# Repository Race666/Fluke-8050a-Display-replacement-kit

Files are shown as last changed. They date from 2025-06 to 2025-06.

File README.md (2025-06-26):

# Yet another Fluke 8050a Display replacement kit

There already several cool other projects for a creating a new display for this type of multimeter where the LCD display is broken.

Here are some examples. 
* [vondervotteimittiss.de](https://www.vondervotteimittiss.de/post/a-new-led-display-for-a-fluke-8050a-multimeter)
* [sps-wagner.de](https://www.sps-wagner.de/Sonstiges/8050A.html)
* [hackaday.com](https://hackaday.com/2022/06/17/hacking-a-new-display-into-a-fluke-8050a-multimeter/)

Based on their work I created my own version. My goal was to create a solution that is easy to install.

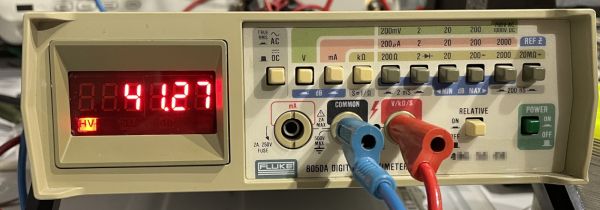
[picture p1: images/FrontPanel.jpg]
My LED Solution


 So the honer for reverse engineering of the 8050a goes to [Michael Damkier](https://www.vondervotteimittiss.de/) and also to [jasonacox](https://github.com/jasonacox) for the TM1637TinyDisplay library on which my project based.

My project uses an Atmel atmega328p microcontroller which I used for other [projects](https://github.com/Race666/masterclock) too.

The precompiled firmware file could be found [here](./src/pio/.pio/build/ATmega328P/firmware.hex)

Flash the with these fuses (8MHz internal clock)
```
avrdude -c usbtiny -p atmega328p -U lfuse:w:0x62:m -U hfuse:w:0xDE:m -U efuse:w:0x05:m -U flash:w:./src/pio/.pio/build/ATmega328P/firmware.hex
```

Overview over the project folders
| Folder  | Description  |
|---|---|
|[/images](./images)|Images for this wiki|
|[/LogicAnalysis](./LogicAnalysis)|Images with Pulseview Screenshots|
|[/pcb](./pcb)|KiCad project with schematic and PCB|
|[/src](./src)|Platform IO firmware project for atmega328p|
|[/stl](./stl)|3D Data for display- and heatsink holder|

The project has multipe parts

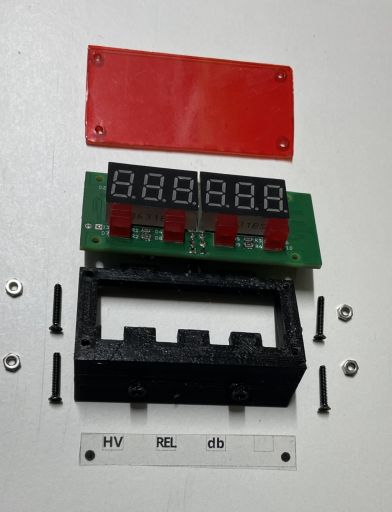
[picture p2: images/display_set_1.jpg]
Parts overview Display set

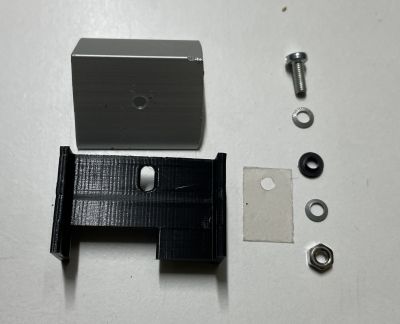
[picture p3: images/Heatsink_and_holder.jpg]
Parts overview Heatsink for -5V regulator

* The platform IO firmware [project](./src/) for the atmega328p microcontroller
* 4 Layer display [PCB](./pcb/) create with KiCad
* A [Display holder](./stl/Fluke%208050a%20Displayhalter.stl) STL for printing by a 3D printer so that the display exctly fits in :-)
* A [holder](./stl/Halter%20Kühlkörper.stl) for a heat sink for the -5V regulator on the mainboard. The Display board consumes more power then the LCD Display so the -5V regulator needs some cooling

In addition to [vondervotteimittiss.de](https://www.vondervotteimittiss.de/post/a-new-led-display-for-a-fluke-8050a-multimeter) I also analysed the logic of the J1 connector from the Fluke display board. I traced the signals by a Hantek logic analyser and pulseview. The traces can be shows [here](./LogicAnalysis/) and looks like this example (Output Pins are the atmega328p outputs for LED's):

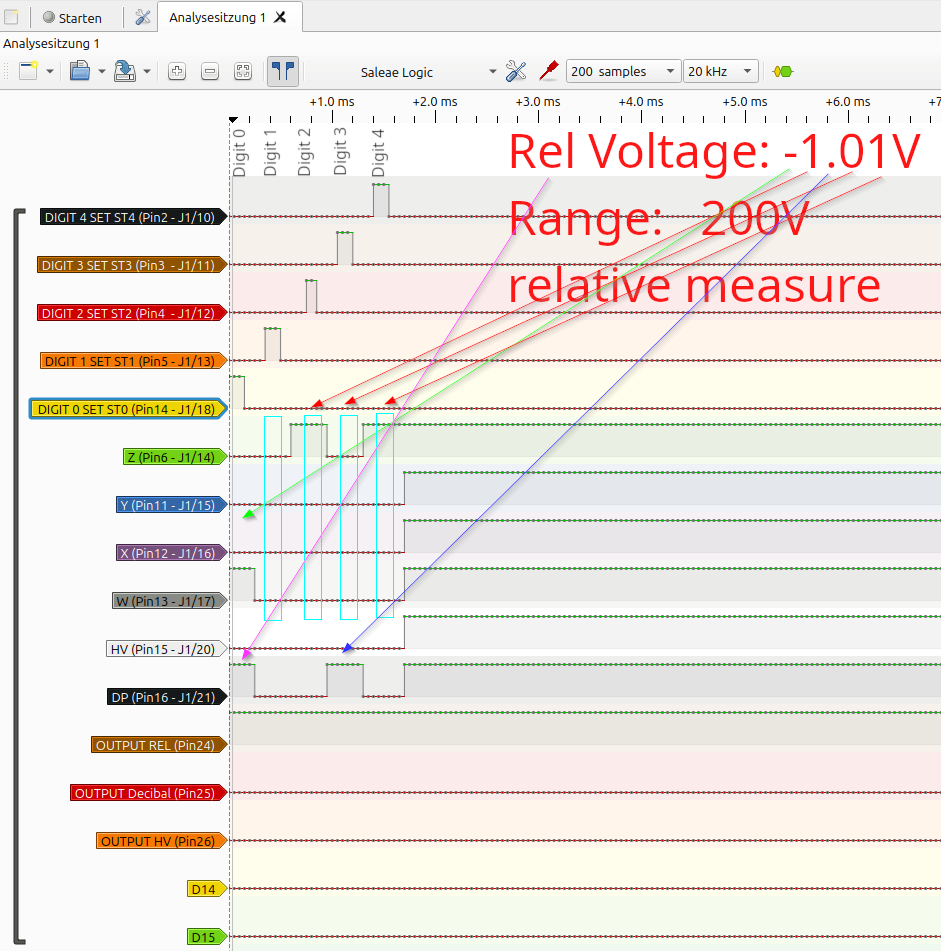
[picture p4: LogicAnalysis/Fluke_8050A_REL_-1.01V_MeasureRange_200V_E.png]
pulseview output


It's always the same format. The DIGIT (select) Pins are corrosponding to the Fluke Display from left to right. 

    Fluke Digit Count
                 _    _    _    _
             |  | |  | |  | |  | | 
         +/-     -    -    -    -
             |  | |  | |  | |  | | 
                 ͞     ͞     ͞     ͞        
     Digit  0    1    2    3    4    

When one of the digit pins get's high the data are submitted by the Pins Z, Y, X, W, HV, DP. A schematic/Service Manual of the Fluke 8050a can be found [here](https://xdevs.com/doc/Fluke/FLUKE%208050A%20Instruction.pdf) or [here](http://manuals.chudov.com/Fluke-8050A.pdf). See Page 7-4, 7-5, the DIGITx signal are labeled as STx in the schematic.

When DIGIT 1-4 are set the Pins Z, Y, X, W represents(as 4Bits) the number which is show at the display. While Z is the LSB (Least Significant Bit) and W the MSB (Most Significant Bit) and the DP signals where to position the decimal point in the display. The decimal point must be shown left to the current transmitted digit. For example (see logic trace) if the DP flag is set in digit 3 then the decimal point is between digit 2 and 3.

DIGIT 0 transfer some more information over Z, Y, X, W, HV, DP.
* HV signals the High Voltage info
* DP in digit 0 signals a relative measure/the relative measure button is locked
* When Z is set "1" is shown at digit postition 0
* When X is not set the measure is negative

| | | | |
|---|---|---|---|
| W=1 | X=1 | Y=0 | Voltage/Current measure |
| W=1 | X=0 | Y=0 | negative Voltage/Current measure | 
| W=1 | X=0 | Y=1 | Decibel measure |
| W=0 | X=0 | Y=0 | Resistor measure |

## The LED display board
The LED display board is a 4 layer PCB created by [KiCad](https://www.kicad.org "Great tool"). Where I used very common parts:
* Atmega328p microcontroller
* TM1637 LED 7 segment driver
* 3361BS 7 segment displays

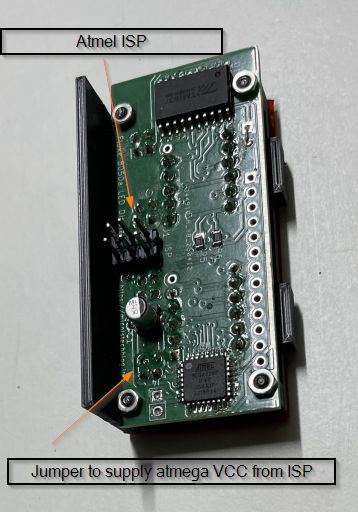
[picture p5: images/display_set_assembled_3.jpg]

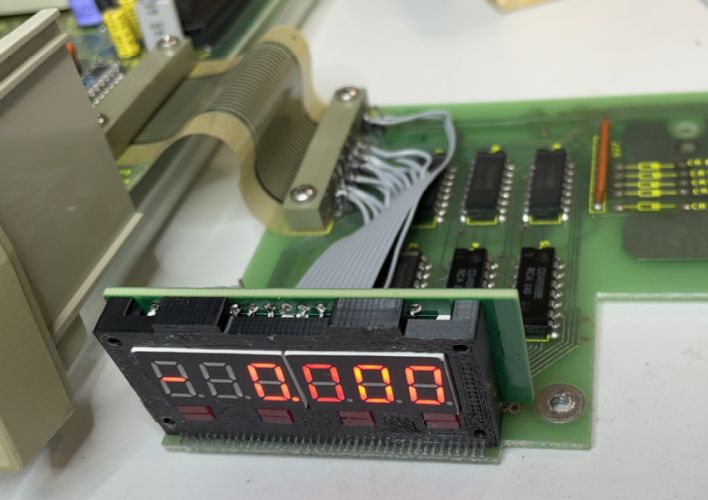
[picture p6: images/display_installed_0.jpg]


The display board has 4 Leds below the 7 segment displays to signal high voltage, decibel and relative measure.

The 6 Pin header is an atmega ISP port.
| Pin | Signal |
|---|---|
|1| MISO |
|2|VCC|
|3|SCK|
|4|MOSI|
|5|RST|
|6|GND|

The header pins for connecting to the fluke display board are ordered so wiring is simple:
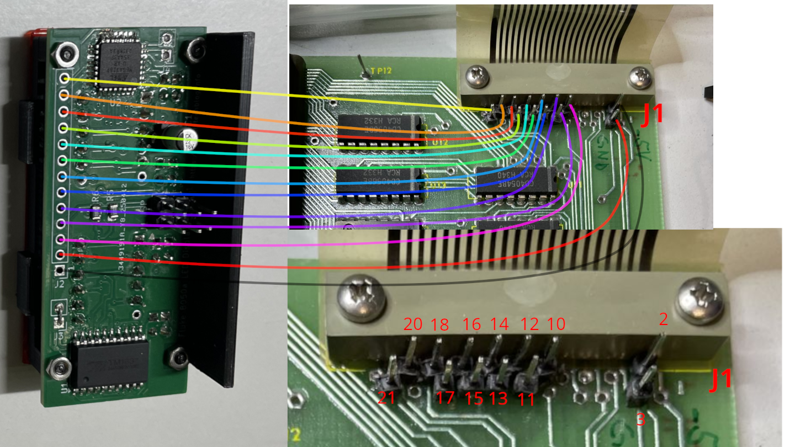
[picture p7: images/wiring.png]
Wiring


## 3D printer parts

### Holder for the PCB

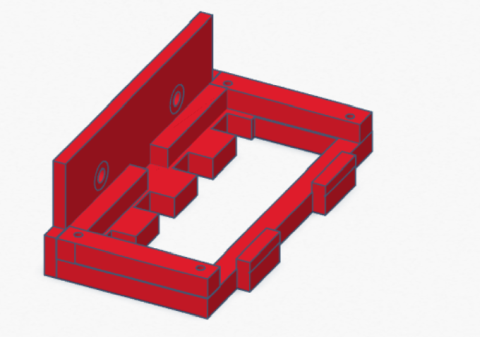
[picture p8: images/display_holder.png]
PCB/Display Holder


### Heatsinkholder/stabilizer
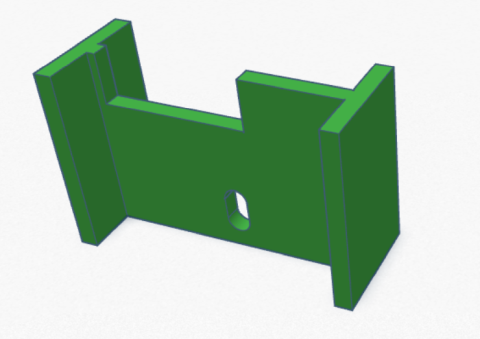
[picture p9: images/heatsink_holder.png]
Heatsink Holder

Heatsink Holder
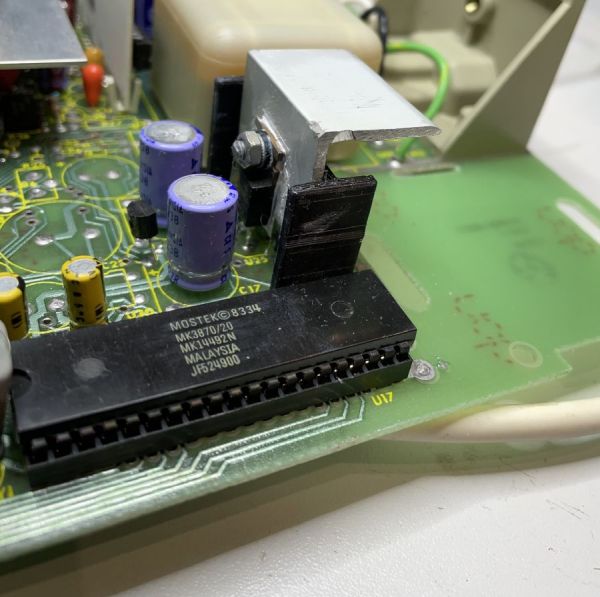
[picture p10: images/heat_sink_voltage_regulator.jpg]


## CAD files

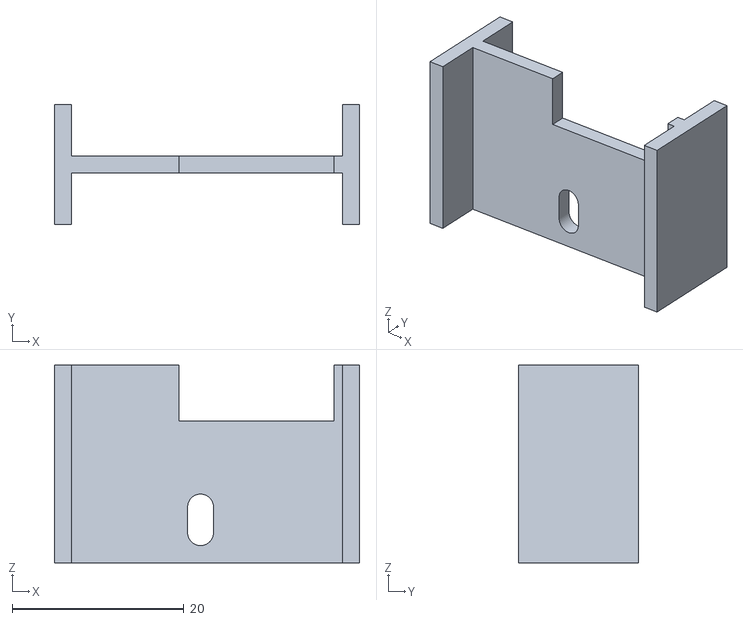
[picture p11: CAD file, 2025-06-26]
stl/Halter Kühlkörper.stl
35.5 x 14.0 x 23.0

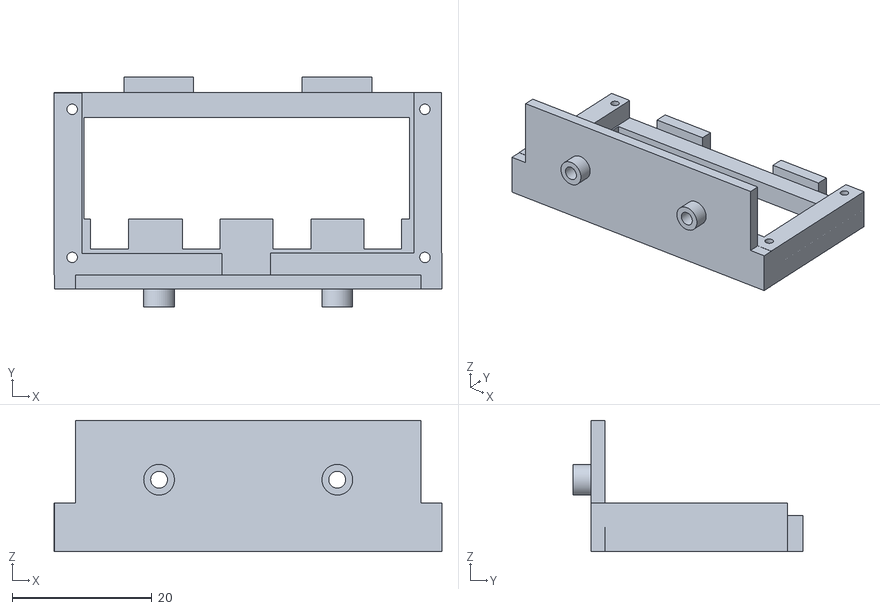
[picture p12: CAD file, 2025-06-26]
stl/Fluke 8050a Displayhalter.stl
55.5 x 33.0 x 18.8

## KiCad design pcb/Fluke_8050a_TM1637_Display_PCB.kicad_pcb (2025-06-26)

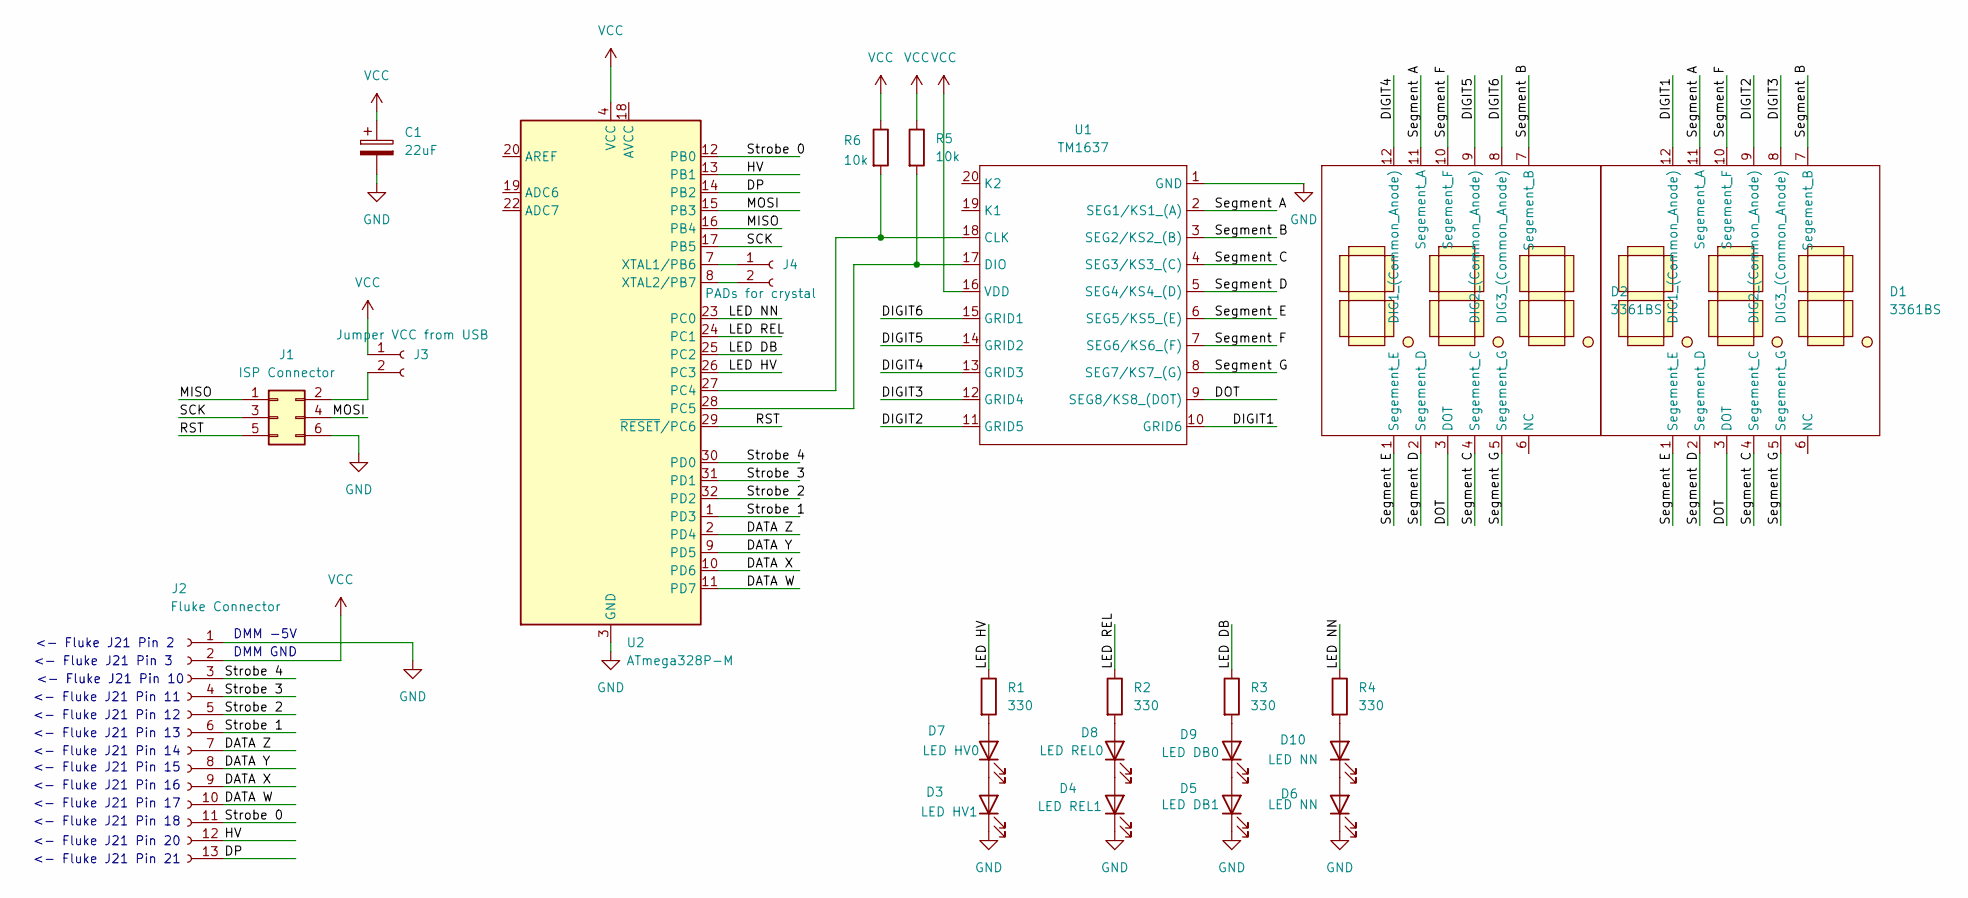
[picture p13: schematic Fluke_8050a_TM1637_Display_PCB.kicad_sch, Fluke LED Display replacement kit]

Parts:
C1: 22uF; CP_Elec_4x5.8
D1, D2: 3361BS; 3361xS
D3: LED HV1; LED 5x2mm Exact
D4: LED REL1; LED 5x2mm Exact
D5: LED DB1; LED 5x2mm Exact
D6, D10: LED NN; LED 5x2mm Exact
D7: LED HV0; LED 5x2mm Exact
D8: LED REL0; LED 5x2mm Exact
D9: LED DB0; LED 5x2mm Exact
J1: ISP Connector; PinHeader_2x03_P2.54mm_Vertical
J2: Fluke Connector; PinHeader_1x13_P2.54mm_Vertical
J3: Jumper VCC from USB; PinHeader_1x02_P2.54mm_Vertical
J4: PADs for crystal; PinHeader_1x02_P2.54mm_Vertical
R1, R2, R3, R4: 330; R_0805_2012Metric
R5, R6: 10k; R_0805_2012Metric
U1: TM1637; SOP-20_7.5x12.8mm_P1.27mm
U2: ATmega328P-M; LQFP-32_7x7mm_P0.8mm

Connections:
/DATA W: J2.10, U2.11 (PD7)
/DATA X: J2.9, U2.10 (PD6)
/DATA Y: J2.8, U2.9 (PD5)
/DATA Z: J2.7, U2.2 (PD4)
/DIGIT1: D1.12 (DIG1_(Common_Anode)), U1.10 (GRID6)
/DIGIT2: D1.9 (DIG2_(Common_Anode)), U1.11 (GRID5)
/DIGIT3: D1.8 (DIG3_(Common_Anode)), U1.12 (GRID4)
/DIGIT4: D2.12 (DIG1_(Common_Anode)), U1.13 (GRID3)
/DIGIT5: D2.9 (DIG2_(Common_Anode)), U1.14 (GRID2)
/DIGIT6: D2.8 (DIG3_(Common_Anode)), U1.15 (GRID1)
/DOT: D1.3 (DOT), D2.3 (DOT), U1.9 (SEG8/KS8_(DOT))
/DP: J2.13, U2.14 (PB2)
/HV: J2.12, U2.13 (PB1)
/LED DB: R3.1, U2.25 (PC2)
/LED HV: R1.1, U2.26 (PC3)
/LED NN: R4.1, U2.23 (PC0)
/LED REL: R2.1, U2.24 (PC1)
/MISO: J1.1, U2.16 (PB4)
/MOSI: J1.4, U2.15 (PB3)
/RST: J1.5, U2.29 (~RESET/PC6)
/SCK: J1.3, U2.17 (PB5)
/Segment A: D1.11 (Segement_A), D2.11 (Segement_A), U1.2 (SEG1/KS1_(A))
/Segment B: D1.7 (Segement_B), D2.7 (Segement_B), U1.3 (SEG2/KS2_(B))
/Segment C: D1.4 (Segement_C), D2.4 (Segement_C), U1.4 (SEG3/KS3_(C))
/Segment D: D1.2 (Segement_D), D2.2 (Segement_D), U1.5 (SEG4/KS4_(D))
/Segment E: D1.1 (Segement_E), D2.1 (Segement_E), U1.6 (SEG5/KS5_(E))
/Segment F: D1.10 (Segement_F), D2.10 (Segement_F), U1.7 (SEG6/KS6_(F))
/Segment G: D1.5 (Segement_G), D2.5 (Segement_G), U1.8 (SEG7/KS7_(G))
/Strobe 0: J2.11, U2.12 (PB0)
/Strobe 1: J2.6, U2.1 (PD3)
/Strobe 2: J2.5, U2.32 (PD2)
/Strobe 3: J2.4, U2.31 (PD1)
/Strobe 4: J2.3, U2.30 (PD0)
GND: C1.2, D3.1 (K), D4.1 (K), D5.1 (K), D6.1 (K), J1.6, J2.1, U1.1 (GND), U2.3 (GND), U2.5 (GND), U2.21 (GND), U2.33 (GND)
unnamed: D3.2 (A), D7.1 (K)
unnamed: D4.2 (A), D8.1 (K)
unnamed: D5.2 (A), D9.1 (K)
unnamed: D7.2 (A), R1.2
unnamed: D8.2 (A), R2.2
unnamed: D9.2 (A), R3.2
unnamed: D10.2 (A), R4.2
unnamed: D6.2 (A), D10.1 (K)
unnamed: J1.2, J3.2
unnamed: J4.1, U2.7 (XTAL1/PB6)
unnamed: J4.2, U2.8 (XTAL2/PB7)
unnamed: R6.2, U1.18 (CLK), U2.27 (PC4)
unnamed: R5.2, U1.17 (DIO), U2.28 (PC5)
VCC: C1.1, J2.2, J3.1, R5.1, R6.1, U1.16 (VDD), U2.4 (VCC), U2.6 (VCC)

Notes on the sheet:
<- Fluke J21 Pin 17
<- Fluke J21 Pin 12
<- Fluke J21 Pin 13
<- Fluke J21 Pin 20
<- Fluke J21 Pin 18
<- Fluke J21 Pin 21
<- Fluke J21 Pin 16
<- Fluke J21 Pin 11
DMM -5V
DMM GND
<- Fluke J21 Pin 3
<- Fluke J21 Pin 10
<- Fluke J21 Pin 2
<- Fluke J21 Pin 15
<- Fluke J21 Pin 14

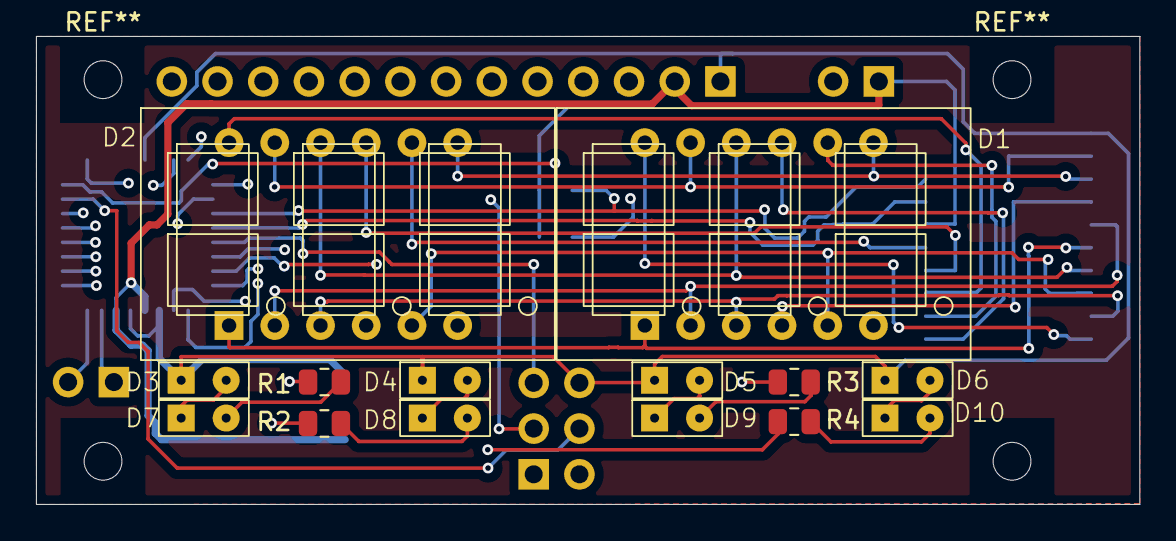
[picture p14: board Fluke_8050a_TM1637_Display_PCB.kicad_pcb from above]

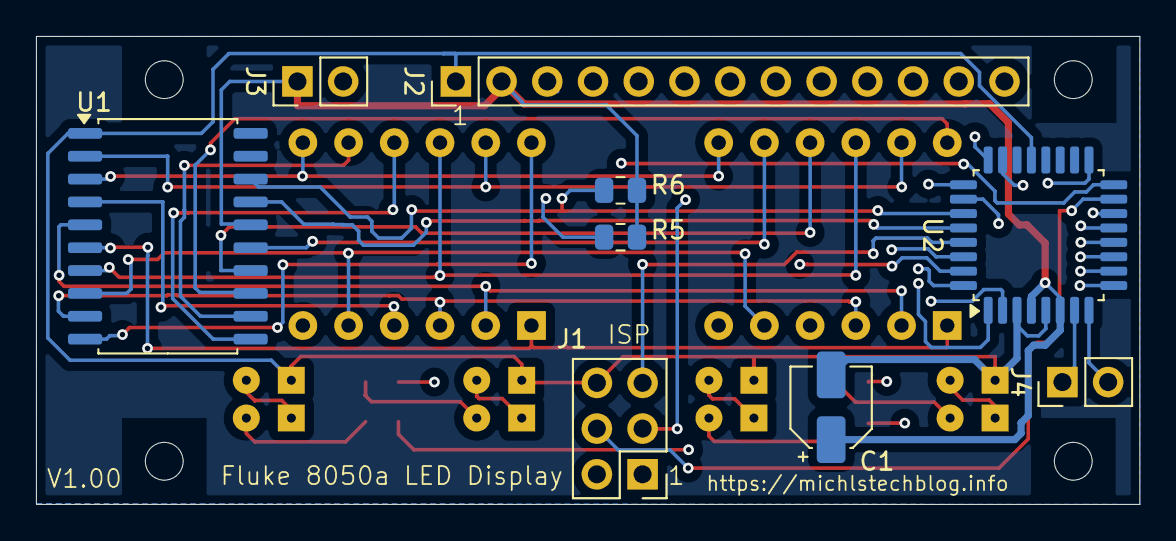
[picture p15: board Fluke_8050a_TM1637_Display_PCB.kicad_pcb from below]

Board: 4 copper layers, 61.3 x 26.0 mm, 23 parts (9 on the bottom side), 48 nets.

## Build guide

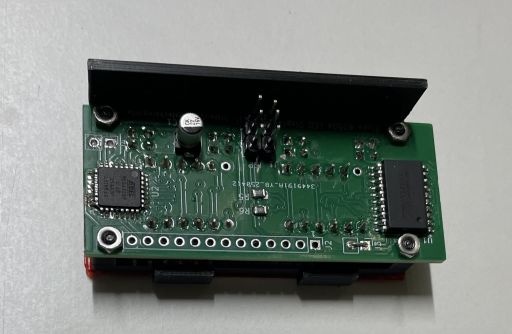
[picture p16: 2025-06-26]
images/display_set_assembled_2.jpg

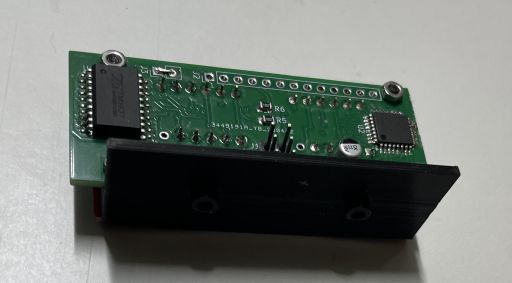
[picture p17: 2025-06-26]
images/display_set_assembled_5.jpg

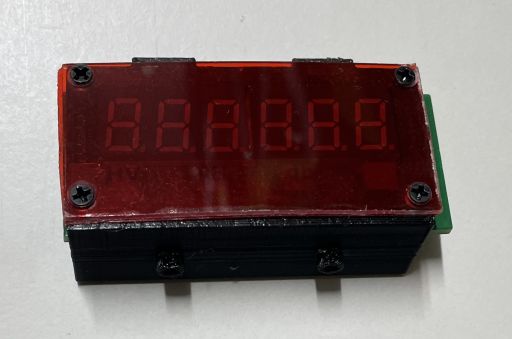
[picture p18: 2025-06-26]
images/display_set_assembled_1.jpg

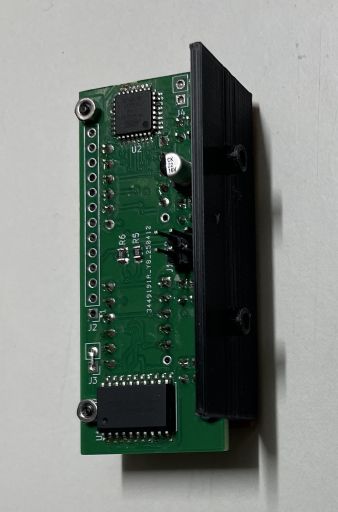
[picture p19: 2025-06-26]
images/display_set_assembled_4.jpg

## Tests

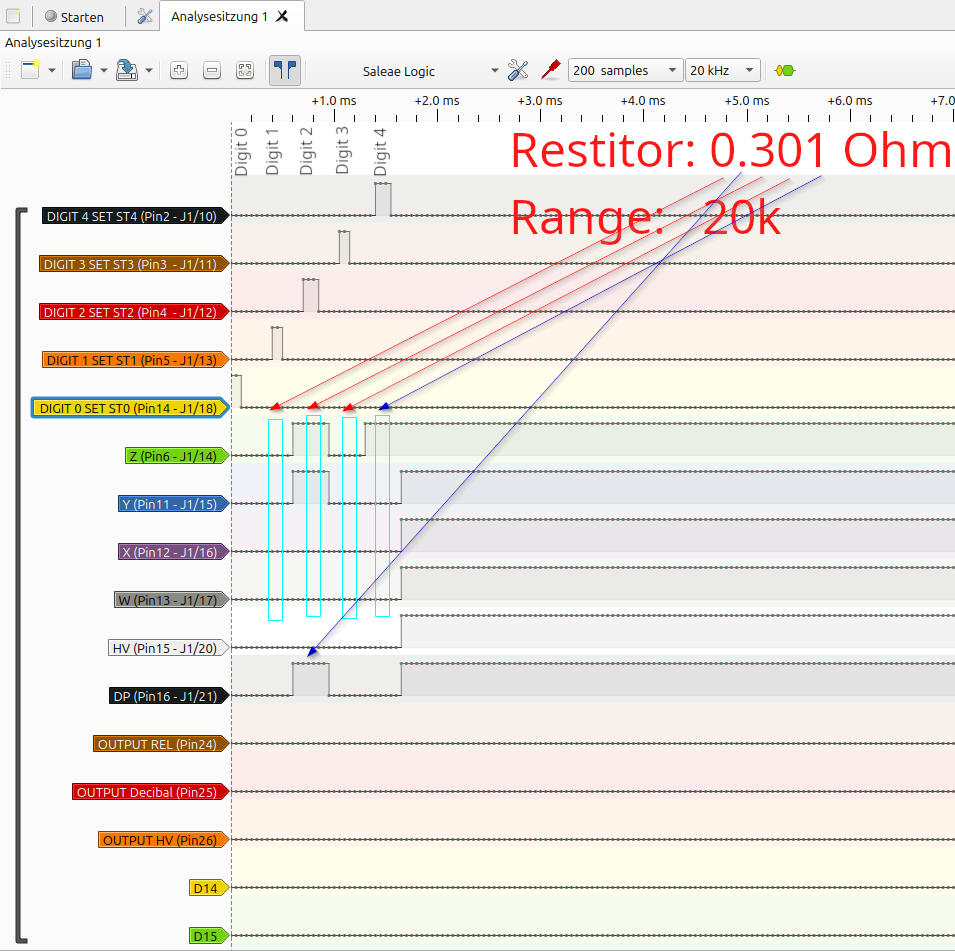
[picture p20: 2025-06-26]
LogicAnalysis/Fluke_8050A_Resistor_300Ohm_MeasureRange_20k_E.png

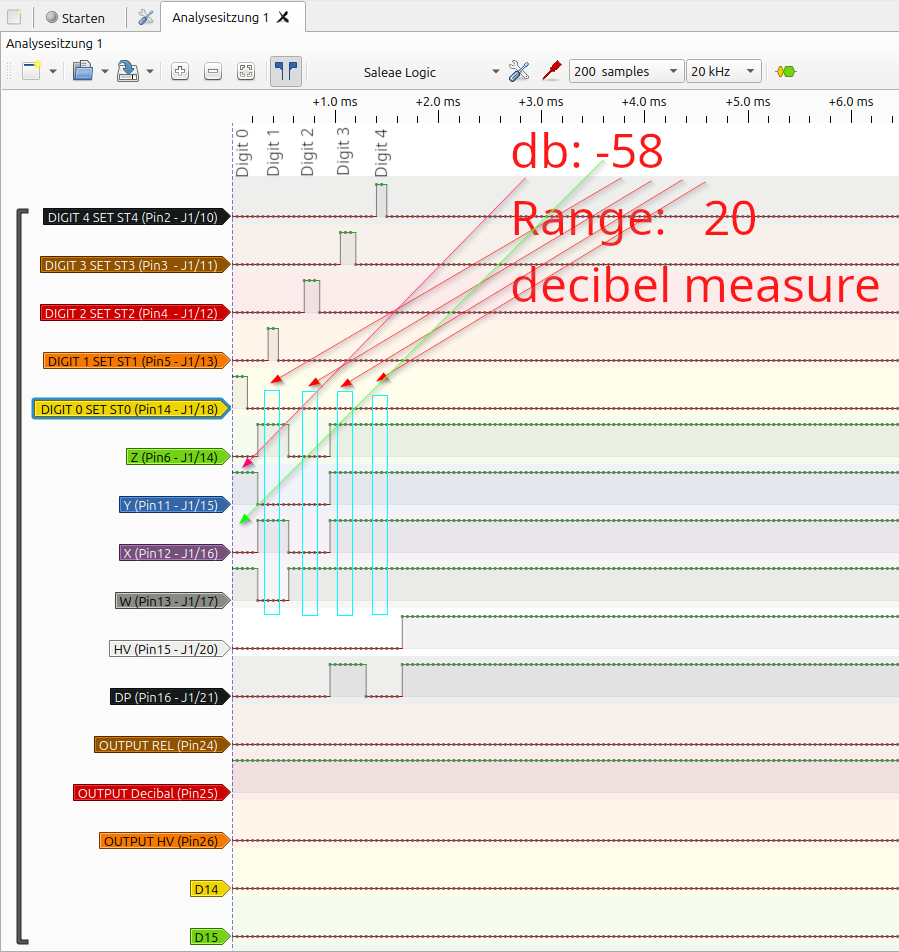
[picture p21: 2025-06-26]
LogicAnalysis/Fluke_8050A_db_-58db_MeasureRange_20_E.png

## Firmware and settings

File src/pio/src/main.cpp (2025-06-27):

#include <Arduino.h>
/*
  TM1637 LED display implementation for Fluke 8050A multimeter

  Honer to https://www.vondervotteimittiss.de/post/a-new-led-display-for-a-fluke-8050a-multimeter
  and https://github.com/jasonacox/TM1637TinyDisplay

  20250312 Michael Albert michael@albert-hetzles.de

  TM1637TinyDisplay => Cannot add by add library function. Not the latest version available in Arduino
  TM1637TinyDisplay Installed by
  cd src
  git clone https://github.com/jasonacox/TM1637TinyDisplay
  delete all expect TM1637TinyDisplay6.*


   avrdude location: 
   & C:\users\$ENV:USERNAME\.platformio\packages\tool-avrdude\avrdude.exe -c usbtiny -p m328p -C ../etc/avrdude.conf -U lfuse:w:0x62:m -U hfuse:w:0xDE:m -U efuse:w:0x05:m

   But use https://github.com/avrdudes/avrdude/releases
   Arduino atmega328p default fuses: -U lfuse:w:0xFF:m -U hfuse:w:0xDE:m -U efuse:w:0x05:m
   D:\tools\Avrdude\avrdude.exe -c usbtiny -p atmega328p -v

   Internal Clock 8Mhz
   D:\tools\Avrdude\avrdude.exe -c usbtiny -p atmega328p -U lfuse:w:0x62:m -U hfuse:w:0xDE:m -U efuse:w:0x05:m -U flash:w:.pio\build\ATmega328P\firmware.hex

   read FUSES
   Fuse calc
   https://eleccelerator.com/fusecalc/fusecalc.php?chip=atmega328p
   D:\tools\Avrdude\avrdude.exe -c usbtiny -p atmega328p -v -U lfuse:r:-:i -U hfuse:r:-:i


   Fluke J1 Connector
   J1 Pin

  Function

    2    -5V
    3    GND
    6     Batt Vref
    10   ST4
    11   ST3
    12   ST2
    13   ST1
    14   Z
    15   Y
    16   X
    17   W
    18   ST0
    20   HV
    21   DP
*/


/* Mapping Fluke J1 => Atmega328p 
  J1     ATMEGA      ArduinoPIN  AtmelPhysical PIN (DIP28) AtmelPhysical PIN (DIP28)

  10  -> PortD Pin0  0           2
  11  -> PortD Pin1  1           3
  12  -> PortD Pin2  2           4
  13  -> PortD Pin3  3           5
  14  -> PortD Pin4  4           6
  15  -> PortD Pin5  5           11
  16  -> PortD Pin6  6           12
  17  -> PortD Pin7  7           13
  18  -> PortB Pin0  8           14
  20  -> PortB Pin1  9           15
  21  -> PortB Pin2  10          16
*/


#include <TM1637TinyDisplay6.h>

// PIN ASSIGNMENTS https://docs.arduino.cc/retired/hacking/software/PortManipulation/
// https://docs.arduino.cc/retired/hacking/hardware/ATMEGA328P/
// Digital Pins
// PortD 0-7 Pin 0-7
// PortB 0-7 Pin 8-13
// PortC 0-5 Pin 14-19
// 8050A strobe lines
// Fluke Digit Count
//             _    _    _    _
//         |  | |  | |  | |  | | 
//     +/-     -    -    -    -
//         |  | |  | |  | |  | | 
//             ͞     ͞     ͞     ͞        
// Digit  0    1    2    3    4    
// Digit Select Input Ports => Interrupt for reading Datalines
#define PORTB_0 8
#define PIN_DIGIT0_ST0 PORTB_0
#define PIN_DIGIT1_ST1 PORTD3
#define PIN_DIGIT2_ST2 PORTD2
#define PIN_DIGIT3_ST3 PORTD1
#define PIN_DIGIT4_ST4 PORTD0


// 8050A Data/Scancode lines Input Pins
#define PIN_DATA_Z 4             // PORTD4 / Phys PIN 6 / Digit Value 2^0 Digit Bit 0
#define PIN_DATA_Y 5             // PORTD5 / Phys PIN 11 / Digit Value 2^1 Digit Bit 1
#define PIN_DATA_X 6             // PORTD6 / Phys PIN 12 / Digit Value 2^2 Digit Bit 2
#define PIN_DATA_W 7             // PORTD7 / Phys PIN 13 / Digit Value 2^3 Digit Bit 3
#define PIN_DATA_HV 9            // PORTB1 / Phys PIN 15
#define PIN_PORTB_HV PORTB1 // PORTB1 / Phys PIN 15
#define PIN_DATA_DP 10           // PORTB2 / Phys PIN 16
#define PIN_PORTB_DP PORTB2 // PORTB2 / Phys PIN 16

// CONSTANTS
// strobe lines (digit/number position) ST0 left (+/- 1) to right ST4
/*  
  example: -1.4567
  scanCodes[ST0] contains
  -1         .4   5   6   7
  ST0       ST1 ST2 ST3 ST4

  The point is to the left of a Digit means it is in the scan code of the next Digit => here ST1, Bit 
  ST5 contains

*/
// Data Bits
#define DATA_SCANCODE_Z_BIT0 0 // 2^0 Digit Bit 0
#define DATA_SCANCODE_Y_BIT1 1 // 2^1 Digit Bit 1
#define DATA_SCANCODE_X_BIT2 2 // 2^2 Digit Bit 2
#define DATA_SCANCODE_W_BIT3 3 // 2^3 Digit Bit 3
// #define DATA_SCANCODE_HV 4
#define DATA_SCANCODE_DP 5

#define SCANCODE_DB DATA_SCANCODE_Y_BIT1
#define SCANCODE_1 DATA_SCANCODE_Z_BIT0
#define SCANCODE_PLUS DATA_SCANCODE_W_BIT3
#define SCANCODE_MINUS DATA_SCANCODE_X_BIT2
#define SCANCODE_REL DATA_SCANCODE_DP

// Output LED Pins HV (HighValtage), db (Decibel), Rel (reltive measure)
#define PIN_PORTC_3 17    // PORTC3 Phy. PIN 26
#define PIN_LED_HV PIN_PORTC_3
#define PIN_PORTC_2 16    // PORTC2 Phy. PIN 25
#define PIN_LED_DB PIN_PORTC_2
#define PIN_PORTC_1 15    // PORTC1 Phy. PIN 24
#define PIN_LED_REL PIN_PORTC_1
// NN (not named LED) => currently not used
#define PIN_PORTC_0 14    // PORTC1 Phy. PIN 23
#define PIN_LED_NN PIN_PORTC_0


// Global variables

// Define TM1637 Pins => PortB Pin3 und 4 => 11, 12
#define PIN_CLK 18    // Atmega phys. PORTC4 PIN27
#define PIN_DIO 19    // Atmega phys. PORTC5 PIN28

// TM1637TinyDisplay6 display(PIN_CLK, PIN_DIO,0,0);
TM1637TinyDisplay6 display(PIN_CLK, PIN_DIO,0,0);

// number of digits in the display
#define NUM_DIGITS 5
// Point Bit 7 of the Scan code of a digit
// #define LED_SEGMENT_DP B10000000
// 5 Digits. Left to right
volatile uint8_t digits[ NUM_DIGITS ] = {
  0,
  0,
  0,
  0,
  0
}; 

// Measure +/-
volatile bool NegativeMeasure=false;
// HighVoltage
volatile bool HighVoltageRockNRoll=false;
// Decibalmeasure
volatile bool DecibalMeasure=false;
// Relative measure
volatile bool Relativemeasure=false;
String sOutputString="";

// Decimal Point Position
volatile uint8_t iDecimalPointPosition=0;

// update display flag (ISR)
volatile boolean displayUpdate = false;


// Digit 6 => 
// Pin Change Interrupts
// Enable pin change interrupts in the PCICR Pin Change Interrupt Control Register
// by setting the appropriate PCIEn Pin Change Interrupt Enable bit(s)
//   PCIE0 enables Arduino pins 8-13, mask bits PCINT0-5
//   PCIE1 enables Arduino pins A0-A5, mask bits PCINT8-13
//   PCIE2 enables Arduino pins 0-7, mask bits PCINT16-23
// Set the desired pin(s) in the appropriate PCMSKn Pin Change Mask Register
//   PCMSK0 handles bits PCINT0-5 PortB
//   PCMSK1 handles bits PCINT8-13 PortC
//   PCMSK2 handles bits PCINT16-23 PortD
//
// Control register enable interrupt enable bit => Port B and D
#define STROBE_INTERRUPT_ENABLE _BV( PCIE0 ) | _BV( PCIE2 );
// pin change mask register
// https://arduino.stackexchange.com/questions/79690/assign-an-interrupt-to-any-pin-of-the-atmega328-microcontroller
#define STROBE_INTERRUPT_MASK_REGISTER_PORTB PCMSK0
#define STROBE_INTERRUPT_MASK_REGISTER_PORTD PCMSK2
// Interrupt vectors/functions
// The ISR is called on the vector PCINTn_vect, corresponding PCIEn.
// ISR for PortB
#define DIGIT0_STROBE_INTERRUPT_VECTOR_PORTB PCINT0_vect 
// ISR for PortD
#define DIGIT1_TO_4_STROBE_INTERRUPT_VECTOR_PORTD PCINT2_vect



// FUNCTIONS
// pin change interrupt service routine
// Interrupt on Digit/Strobe 0  PortB0
ISR( DIGIT0_STROBE_INTERRUPT_VECTOR_PORTB )
{
  // Read IO Ports
  uint8_t ReadPortD= PIND ;
  uint8_t ReadPortB= PINB ;
  if(digitalRead(PIN_DIGIT0_ST0))
  {
    // The upper 4 Bit of PortD. Die lower 4 are the Digit selectors and not necessary here
      ReadPortD=(ReadPortD & 0xf0);
    // Right shift, to shift out Strobe 1-4 from PortD
    ReadPortD=(ReadPortD>>4);
    // Is voltage/current measure and negativ mumber?
    if (ReadPortD & (1<< SCANCODE_PLUS) && ReadPortD & (1<< SCANCODE_MINUS))
      NegativeMeasure=false;
    // resistor measure
    else if((ReadPortD & (1<< SCANCODE_PLUS))==0)  
      NegativeMeasure=false;
    else
      NegativeMeasure=true;
    // Leading 1 for example 12.345
    if(ReadPortD & (1<<SCANCODE_1))
    {
      digits[0]=1;
    } 
    else
      digits[0]=0;
    // Decibal measure?   
    if(ReadPortD & (1<<SCANCODE_DB))
      DecibalMeasure=true;
    else
      DecibalMeasure=false;      
    // HighVoltage  
    if(ReadPortB & (1<<PIN_PORTB_HV))
      HighVoltageRockNRoll=true;
    else
      HighVoltageRockNRoll=false;
    // Relative measure    
    if(ReadPortB & (1<<PIN_PORTB_DP))
       Relativemeasure=true;
    else
      Relativemeasure=false;       
  }  
}

// Interrupt for Digit/Strobe 1 - 4 selector
ISR( DIGIT1_TO_4_STROBE_INTERRUPT_VECTOR_PORTD )
{
  uint8_t DigitPosition=0;
  // Read IO Ports
  uint8_t ReadPortD= PIND ;
  uint8_t ReadPortB= PINB ;
  // Digit 1?
  if(ReadPortD & (1<<PIN_DIGIT1_ST1))
  {
    DigitPosition=1;
    digits[1] = (ReadPortD & B11110000) >>4; 
  }
  // Digit 2?
  else if(ReadPortD & (1<<PIN_DIGIT2_ST2))
  {
    DigitPosition=2;
    digits[2] = (ReadPortD & B11110000) >>4; 
  }
  // Digit 3?
  else if(ReadPortD &  (1<<PIN_DIGIT3_ST3))
  {
    DigitPosition=3;
    digits[3] = (ReadPortD & B11110000) >>4; 
  }
  // Digit 4?
  else if(ReadPortD & (1<<PIN_DIGIT4_ST4))
  {
    DigitPosition=4;
    digits[4] = (ReadPortD & B11110000) >>4; 
  }
  // Decimal Point set? The decimal point bit is set on at the digit after that point
  if(ReadPortB & (1<<PORTB2) && DigitPosition>=1 && DigitPosition<=4)
  {
    iDecimalPointPosition=5-DigitPosition;
  }
  // Last digit (4) read => Update display
  if(DigitPosition==4)
  {
    displayUpdate=true;
  }
}

void formatOutput()
{
  if(NegativeMeasure)
    sOutputString="-";
  else
    sOutputString=" "; 
  if(digits[0]==1)
    sOutputString+="1"; 
  else
    sOutputString+=" ";   
  // Digit 1-4 to output string  
  for ( uint8_t i = 1; i <= 4; i++ )
  {
    // Special case Resistormeasure, 7 Segment shows no number
    if(digits[i]==0xf)
      sOutputString+=String(" ");
    else
      // Number to outputstring
      sOutputString+=String(digits[i], DEC);
  }
  // Special case not valid measure range
  if(digits[0]==0 && digits[1]==0xf && digits[2]==0xf && digits[3]==0xf && digits[4]==0xf)
  {
    sOutputString=String("------");
    iDecimalPointPosition=0;
  }
  return;
}

// HV - HighVoltage
// db - decibel measure
// Rel- Relative measure
void setStateLEDs()
{
  // indicator LEDs dB, HV, REL
  digitalWrite(PIN_LED_DB, DecibalMeasure );
  // digitalWrite(PIN_LED_HV, HighVoltageRockNRoll); => Switched to blinking
  digitalWrite(PIN_LED_REL, Relativemeasure);
}


void updateDisplay()
{
  // displayUpdate flag is set in the ISR
  if ( displayUpdate )
  {
    displayUpdate = false;
    formatOutput();
    if(iDecimalPointPosition>=1)
      // With decimal point
      display.showString(sOutputString.c_str(),6,0,(1<<(iDecimalPointPosition+2)));
    else
      // No decimal point
      display.showString(sOutputString.c_str(),6,0);
    setStateLEDs();
    iDecimalPointPosition=0;
    // writeDigits();
  }
}  

// Blinking HV LED
void ChangeBlinkLEDState()
{
  if(HighVoltageRockNRoll)
    digitalWrite(PIN_LED_HV, !digitalRead(PIN_LED_HV));
  else
    digitalWrite(PIN_LED_HV,0);  
}

void setup() {
  // disable ADC (to reduce power)
  ADCSRA = 0; 
  // Input DIGIT 0 - 4 set/select
  pinMode(PIN_DIGIT0_ST0,INPUT );
  pinMode(PIN_DIGIT1_ST1,INPUT );
  pinMode(PIN_DIGIT2_ST2,INPUT );
  pinMode(PIN_DIGIT3_ST3,INPUT );
  pinMode(PIN_DIGIT4_ST4,INPUT );
  // Data Pins
  pinMode(PIN_DATA_Z,INPUT );
  pinMode(PIN_DATA_Y,INPUT );
  pinMode(PIN_DATA_X,INPUT );
  pinMode(PIN_DATA_W,INPUT );
  pinMode(PIN_DATA_HV,INPUT );
  pinMode(PIN_DATA_DP,INPUT );
  // LED Pins
  pinMode(PIN_LED_HV,OUTPUT);
  pinMode(PIN_LED_DB,OUTPUT);
  pinMode(PIN_LED_REL,OUTPUT);
  pinMode(PIN_LED_NN,OUTPUT);
  // Initialize Display => Test
  display.begin();
  // display.showString("000000");
  display.showString(" FLUHE");
  digitalWrite(PIN_LED_HV, HIGH);
  delay(50);
  // display.showString("111111");
  display.showString(" 8050A");
  digitalWrite(PIN_LED_HV, LOW);
  digitalWrite(PIN_LED_REL, HIGH);
  delay(50);
  // display.showString("222222");
  display.showString(" V1.00");
  digitalWrite(PIN_LED_REL, LOW);  
  digitalWrite(PIN_LED_DB, HIGH );
  delay(50);
  digitalWrite(PIN_LED_DB, LOW); 
  digitalWrite(PIN_LED_NN, HIGH); 
  delay(50);
  digitalWrite(PIN_LED_NN, LOW); 
  cli();
  // st = ST0; // initialize the strobe counter
  PCICR = STROBE_INTERRUPT_ENABLE;
  // STROBE_INTERRUPT_MASK_REGISTER_PORTB = StrobePin2PCINT[ st ];
  // Interrupt on Digit select / Strobe lines ST1 - S4
  STROBE_INTERRUPT_MASK_REGISTER_PORTD = (1<<PIN_DIGIT1_ST1) | (1<<PIN_DIGIT2_ST2) | (1<<PIN_DIGIT3_ST3) | (1<<PIN_DIGIT4_ST4);
  // Interrupt on Digit 0 select / Strobe lines ST0
  STROBE_INTERRUPT_MASK_REGISTER_PORTB = (1<<PORTB0);
  sei();
}
unsigned long BlinkingLastMills=0;
uint32_t BlinkLEDChangeEveryMilliseconds=25;
void loop() 
{
  // catch millis() overflow
  if(millis() < BlinkingLastMills)
    BlinkingLastMills=millis();

  if(BlinkingLastMills <= millis()-BlinkLEDChangeEveryMilliseconds)
  {
    ChangeBlinkLEDState();
    BlinkingLastMills=millis();
  }
  updateDisplay();
}
